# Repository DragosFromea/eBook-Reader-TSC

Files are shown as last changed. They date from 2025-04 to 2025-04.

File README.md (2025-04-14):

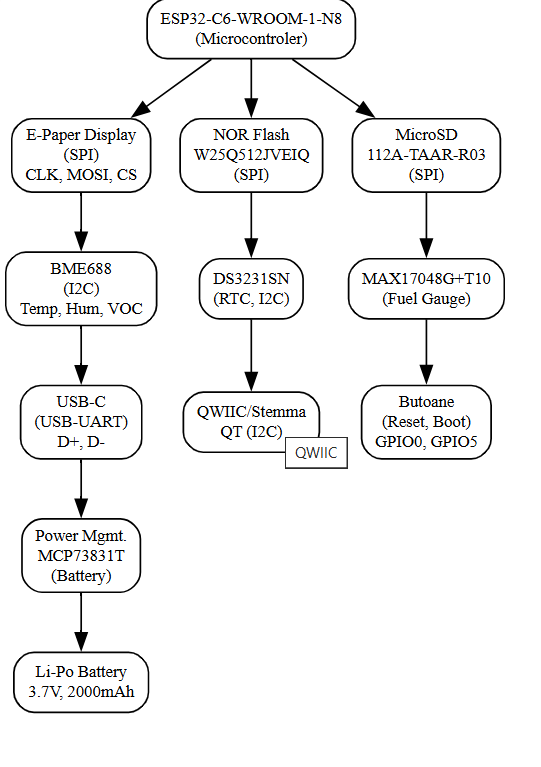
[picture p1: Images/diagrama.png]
Diagrama


| Component | Supplier Link | Datasheet |
|---|---|---|
| 112A-TAAR-R03 ATTEND | -| [Datasheet](https://www.snapeda.com/parts/112A-TAAR-R03/Attend/datasheet/)|
| BD5229G-TR | [Mouser](https://www.mouser.co.uk/ProductDetail/ROHM-Semiconductor/BD5229G-TR?qs=4kLU8WoGk0vvnhrrYwdszw%3D%3D)| [Datasheet](https://fscdn.rohm.com/en/products/databook/datasheet/ic/power/voltage_detector/bd52xxg-e.pdf) |
| CPH3225A (Supercapacitor)| [SnapEDA](https://www.snapeda.com/parts/CPH3225A/Seiko+Instruments/view-part/?ref=eda) | [Datasheet](https://www.snapeda.com/parts/CPH3225A/Seiko%20Instruments/datasheet/) |
| DS3231SN# (RTC) | [SnapEDA](https://www.snapeda.com/parts/DS3231SN%23/Analog+Devices/view-part/?ref=eda) | [Datasheet](https://www.analog.com/media/en/technical-documentation/data-sheets/DS3231.pdf) |
| ESP32-C6-WROOM-1-N8 | [SnapEDA](https://www.snapeda.com/parts/ESP32-C6-WROOM-1-N8/Espressif+Systems/view-part/?ref=eda) | [Datasheet](https://www.espressif.com/sites/default/files/documentation/esp32-c6-wroom-1_datasheet_en.pdf) |
| FH34SRJ-24S-0.5SH99 | [Mouser](https://ro.mouser.com/ProductDetail/Hirose-Connector/FH34SRJ-24S-0.5SH99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) | [Datasheet](https://www.hirose.com/product/document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) |
| MBR0530 (Schottky Diode)| [SnapEDA](https://www.snapeda.com/parts/MBR0530/Onsemi/view-part/?ref=eda) | [Datasheet](https://www.onsemi.com/pdf/datasheet/mbr0530-d.pdf) |
| MAX17048G+T10 (Fuel Gauge)| [SnapEDA](https://www.snapeda.com/parts/MAX17048G+T10/Analog+Devices/view-part/?ref=eda)| [Datasheet](https://www.analog.com/media/en/technical-documentation/data-sheets/MAX17048-MAX17049.pdf) |
| USBLC6-2SC6Y (TVS Diode)| [SnapEDA](https://www.snapeda.com/parts/USBLC6-2SC6Y/STMicroelectronics/view-part/?ref=eda)| [Datasheet](https://www.st.com/resource/en/datasheet/usblc6-2.pdf) |
| W25Q512JVEIQ (Flash) | [SnapEDA](https://www.snapeda.com/parts/W25Q512JVEIQ/Winbond+Electronics/view-part/?ref=eda)| [Datasheet](https://www.winbond.com/resource-files/W25Q512JV%20SPI%20RevB%2006252019%20KMS.pdf) |
| XC6220A331MR-G (LDO) | [Mouser](https://www.mouser.co.uk/ProductDetail/Torex-Semiconductor/XC6220A331MR-G?qs=AsjdqWjXhJ8ZSWznL1J0gg%3D%3D)| [Datasheet](https://product.torexsemi.com/system/files/series/xc6220.pdf) | |
| QWIIC Connector | - | [Datasheet](https://learn.sparkfun.com/tutorials/qwiic-shield-for-arduino--photon-hookup-guide) |

Core Components
Microcontroller (ESP32-C6-WROOM-1-N8):

    Architecture: 32-bit RISC-V

    Clock Speed: 160 MHz

    Wireless: Wi-Fi 6 (2.4 GHz), Bluetooth 5.0

    Functions: System control, sensor/module communication, power management.

Power Management
Battery System:

    Type: Li-Po (Lithium Polymer)

    Capacity: 3.7V, 1800mAh

    Charging Circuit: MCP73831T (5V input via USB-C)

    Protection: Overcharge and deep discharge safeguards.

    Voltage Regulation: LDO regulator (stable 3.3V output).

Storage & Display
E-Paper Display:

    Size: 7.5 inches | Resolution: 800×480 pixels

    Interface: SPI

MicroSD Card Module:

    Format: FAT32 | Interface: SPI

External NOR Flash:

    Capacity: 64MB | Interface: SPI

Sensors & Timing
Environmental Sensor (BME688):

    Metrics: Temperature, humidity, air pressure, gas levels.

    Interface: I2C

Real-Time Clock (DS3231SN):

    Function: Maintains time/date during power loss.

    Interface: I2C

User Interface
USB-C Connector:

    Role: Power input, data transfer.

    Safety: ESD protection + Schottky diode (reverse polarity).

Tactile Push Buttons:

    Control: GPIO-based input.

Communication Interfaces
SPI: SD card, external flash, e-paper display.

I2C: BME688 sensor, DS3231SN RTC.

GPIO: Button controls, general I/O.

UART: Debugging, serial communication.

Wireless: Wi-Fi 6/Bluetooth 5.0 (via ESP32-C6).

### Power Consumption Estimation  
| Component | Current Draw (mA) | Voltage (V) | Power (mW) |  
|---|---|---|---|
| ESP32-C6 (Wi-Fi active) | 200 | 3.3 | 660 |  
| E-Paper Display (Updating) | 40 | 3.3 | 132 |  
| BME688 Sensor (Measuring) | 3.1 | 3.3 | 10.23 |  
| RTC Module (Active) | 0.15 | 3.3 | 0.495 |  
| SD Card (Active) | 50 | 3.3 | 165 |  
| External NOR Flash | 25 | 3.3 | 82.5 |  
| **Total Estimated Power Consumption** | **~318.5 mA** | **3.3** | **1050.72**|  

---

### ESP32-C6 Pin Mapping  
| Component | ESP32-C6 Pin(s) | Interface | Purpose |  
|---|---|---|---|
| E-Paper Display | IO7 (MOSI), IO6 (SCK), IO10 (CS), IO5 (DC), IO23 (RST), IO3 (BUSY) | SPI | Transfers image data to the display and controls its state. |  
| MicroSD Card | IO7 (MOSI), IO6 (SCK), IO4 (SS_SD), IO2 (MISO) | SPI | Storage and retrieval of e-book files. |  
| Environmental Sensor (BME688)  | IO21 (SDA), IO22 (SCL) | I2C | Reads temperature, humidity, pressure, and air quality data. |  
| RTC Module (DS3231) | IO21 (SDA), IO22 (SCL), IO18 (RST), IO1 (32KHz), IO0 (INT_RTC) | I2C | Maintains time/date tracking during system power-off. |  
| External NOR Flash | IO11 (CS), IO6 (SCK), IO2 (MISO), IO7 (MOSI) | SPI | Additional storage for application data. |  
| Battery Monitoring | IO21 (SDA), IO22 (SCL) | I2C | Monitors battery voltage and charge status. |  
| USB-C Connection | GPIOs (via voltage regulation) | USB | Powers and programs the ESP32-C6. |  
| Control Buttons | IO9 (BOOT), IO15 (CHANGE), EN (RESET) | GPIO | User input for device interactions (boot, mode change, reset). |  

Am acceptat erorile SMD de overlap

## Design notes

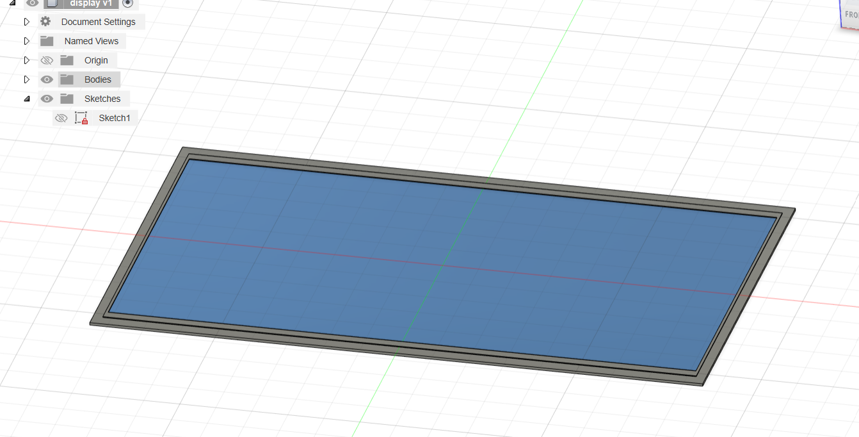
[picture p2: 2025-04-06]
Images/Screenshot 2025-04-06 185428.png

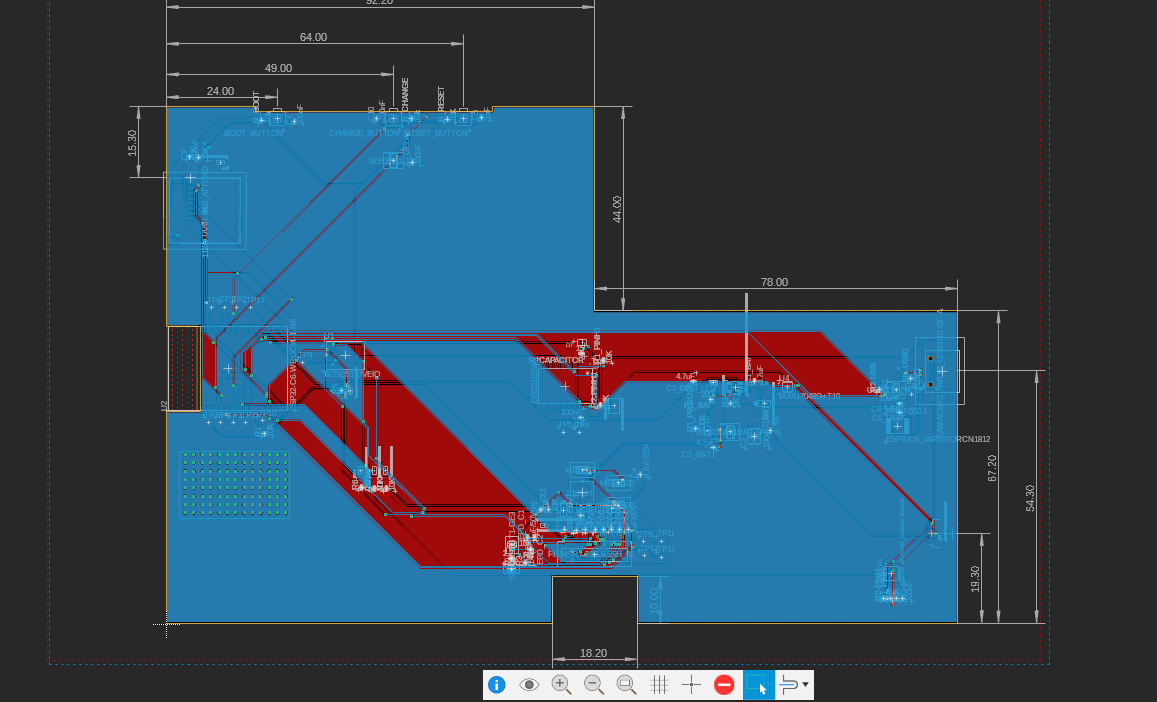
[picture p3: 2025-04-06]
Images/Screenshot 2025-04-06 185200.png

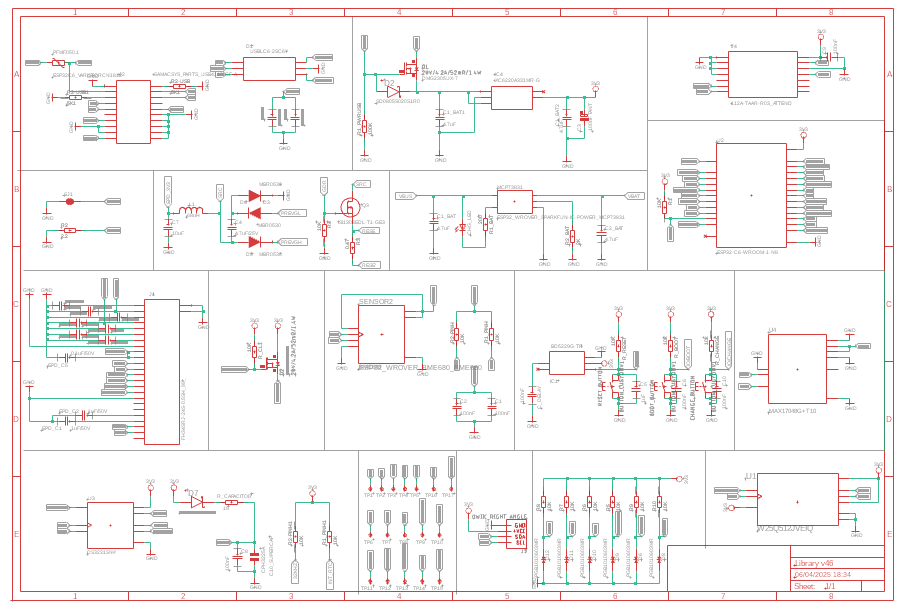
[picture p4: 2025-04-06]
Images/Screenshot 2025-04-06 185306.png

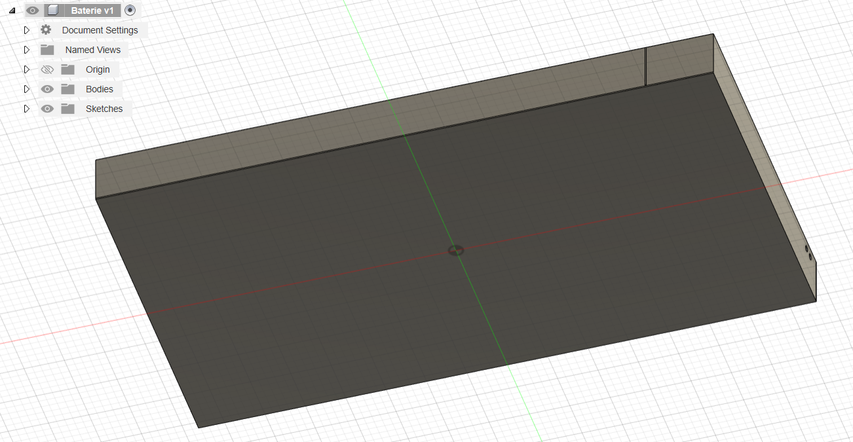
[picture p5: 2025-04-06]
Images/Screenshot 2025-04-06 185601.png

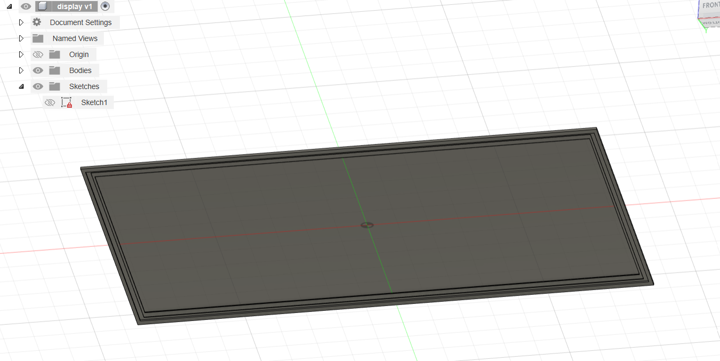
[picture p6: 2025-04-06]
Images/Screenshot 2025-04-06 185456.png

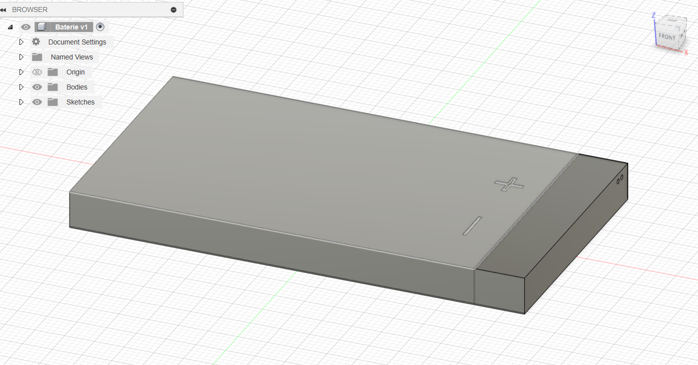
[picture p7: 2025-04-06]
Images/Screenshot 2025-04-06 185522.png

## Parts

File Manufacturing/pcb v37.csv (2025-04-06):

Qty | Value | Device | Package | Parts | Description | ARROW_PART_NUMBER | ARROW_PRICE-STOCK | AVAILABILITY | CENTROID_NOT_SPECIFIED | CHECK_PRICES | COPYRIGHT | DATASHEET | DESCRIPTION | DIGIKEY_DESCRIPTION | DIGIKEY_PART_NUMBER | HEIGHT | LEAD_FREE | MANUFACTURER_NAME | MANUFACTURER_PART_NUMBER | MF | MFR_NAME | MOUSER_PART_NUMBER | MOUSER_PRICE-STOCK | MOUSER_TESTING_PART_NUMBER | MOUSER_TESTING_PRICE-STOCK | MP | MPN | PACKAGE | POPULARITY | PREFIX | PRICE | PROD_ID | PURCHASE-URL | ROHS | SNAPEDA_LINK | SPICEMODEL | SPICEPREFIX | TEMPERATURE_RANGE_HIGH | TEMPERATURE_RANGE_LOW | TP_SIGNAL_NAME | VALUE
1 |  | ADAFRUIT_LEDCHIP-LED0603 | ADAFRUIT_CHIP-LED0603 | CHG_LED | LED
1 |  | SJ | SJ | SJ1 | SMD solder JUMPER |  |  |  |  |  |  |  |  |  |  |  |  |  |  |  |  |  |  |  |  |  |  |  | 3
1 | 0.1uF/50V | ESP32_WROVER_EAGLE-LTSPICE_CC0402 | ESP32_WROVER_EAGLE-LTSPICE_C0402 | EPD_C5 | CAPACITOR, European symbol |  |  |  |  |  |  |  |  |  |  |  |  |  |  |  |  |  |  |  |  |  |  |  |  |  |  |  |  |  |  | NONE | C
1 | 0.47 | ESP32_WROVER_EAGLE-LTSPICE_RR0402 | ESP32_WROVER_EAGLE-LTSPICE_R0402 | R3 | RESISTOR, European symbol |  |  |  |  |  |  |  |  |  |  |  |  |  |  |  |  |  |  |  |  |  |  |  |  |  |  |  |  |  |  | NONE | R
1 | 100K | ESP32_WROVER_EAGLE-LTSPICE_RR0402 | ESP32_WROVER_EAGLE-LTSPICE_R0402 | R1_PWRUSB | RESISTOR, European symbol |  |  |  |  |  |  |  |  |  |  |  |  |  |  |  |  |  |  |  |  |  |  |  |  |  |  |  |  |  |  | NONE | R
8 | 100nF | ESP32_WROVER_EAGLE-LTSPICE_CC0402 | ESP32_WROVER_EAGLE-LTSPICE_C0402 | C1, C2, C4_USB, C6, C8, C9, C10, C_DELAY | CAPACITOR, European symbol |  |  |  |  |  |  |  |  |  |  |  |  |  |  |  |  |  |  |  |  |  |  |  |  |  |  |  |  |  |  | NONE | C
1 | 100uF TANT | RCL_CPOL-EUCT3528 | RCL_CT3528 | C3 | POLARIZED CAPACITOR, European symbol |  |  |  |  |  |  |  |  |  |  |  |  |  |  |  |  |  |  |  |  |  |  |  | 0 |  |  |  |  |  |  |  | C
14 | 10K | ESP32_WROVER_EAGLE-LTSPICE_RR0402 | ESP32_WROVER_EAGLE-LTSPICE_R0402 | R1, R1_PINH, R1_PINH1, R2-PINH, R2-PINH1, R4, R5, R6, R7, R8, R9, R10, R_CL1, R_RESET | RESISTOR, European symbol |  |  |  |  |  |  |  |  |  |  |  |  |  |  |  |  |  |  |  |  |  |  |  |  |  |  |  |  |  |  | NONE | R
2 | 10k | ESP32_WROVER_EAGLE-LTSPICE_RR0402 | ESP32_WROVER_EAGLE-LTSPICE_R0402 | R_BOOT, R_CHANGE | RESISTOR, European symbol |  |  |  |  |  |  |  |  |  |  |  |  |  |  |  |  |  |  |  |  |  |  |  |  |  |  |  |  |  |  | NONE | R
1 | 10uF | ESP32_WROVER_EAGLE-LTSPICE_CC0402 | ESP32_WROVER_EAGLE-LTSPICE_C0402 | C7 | CAPACITOR, European symbol |  |  |  |  |  |  |  |  |  |  |  |  |  |  |  |  |  |  |  |  |  |  |  |  |  |  |  |  |  |  | NONE | C
1 | 112A-TAAR-R03_ATTEND | 112A-TAAR-R03_ATTEND | 112ATAARR03ATTEND | J4 | Micro SD Card Socket, Push-Push Type, Top Mount, SMT, H=1.83mm, 10u |  |  |  |  |  |  |  | Micro SD Card Socket | Push-Push Type | Top Mount | SMT | H=1.83mm | 10u |  |  | 1.9mm |  | ATTEND | 112A-TAAR-R03 ATTEND
1 | 15 | ESP32_WROVER_EAGLE-LTSPICE_RR0402 | ESP32_WROVER_EAGLE-LTSPICE_R0402 | R_CAPACITOR | RESISTOR, European symbol |  |  |  |  |  |  |  |  |  |  |  |  |  |  |  |  |  |  |  |  |  |  |  |  |  |  |  |  |  |  | NONE | R
1 | 1uF | ESP32_WROVER_EAGLE-LTSPICE_CC0402 | ESP32_WROVER_EAGLE-LTSPICE_C0402 | C5 | CAPACITOR, European symbol |  |  |  |  |  |  |  |  |  |  |  |  |  |  |  |  |  |  |  |  |  |  |  |  |  |  |  |  |  |  | NONE | C
1 | 1uF/50 | ESP32_WROVER_EAGLE-LTSPICE_CC0402 | ESP32_WROVER_EAGLE-LTSPICE_C0402 | EPD_C8 | CAPACITOR, European symbol |  |  |  |  |  |  |  |  |  |  |  |  |  |  |  |  |  |  |  |  |  |  |  |  |  |  |  |  |  |  | NONE | C
8 | 1uF/50V | ESP32_WROVER_EAGLE-LTSPICE_CC0402 | ESP32_WROVER_EAGLE-LTSPICE_C0402 | EPD_C1, EPD_C2, EPD_C6, EPD_C7, EPD_C9, EPD_C10, EPD_C11, EPD_C12 | CAPACITOR, European symbol |  |  |  |  |  |  |  |  |  |  |  |  |  |  |  |  |  |  |  |  |  |  |  |  |  |  |  |  |  |  | NONE | C
1 | 2.2 | ESP32_WROVER_EAGLE-LTSPICE_RR0402 | ESP32_WROVER_EAGLE-LTSPICE_R0402 | R2 | RESISTOR, European symbol |  |  |  |  |  |  |  |  |  |  |  |  |  |  |  |  |  |  |  |  |  |  |  |  |  |  |  |  |  |  | NONE | R
1 | 200 | ESP32_WROVER_EAGLE-LTSPICE_RR0402 | ESP32_WROVER_EAGLE-LTSPICE_R0402 | R1_BAT | RESISTOR, European symbol |  |  |  |  |  |  |  |  |  |  |  |  |  |  |  |  |  |  |  |  |  |  |  |  |  |  |  |  |  |  | NONE | R
2 | 20V/4.2A/52mO/1.4W | ESP32_WROVER_SPARKFUN-DISCRETESEMI_MOSFET_PCH-DMG2305UX-7 | ESP32_WROVER_SPARKFUN-DISCRETESEMI_SOT23-3 | Q1, Q2 | P-channel MOSFETs |  |  |  |  |  |  |  |  |  |  |  |  |  |  |  |  |  |  |  |  |  |  |  |  |  |  | TRAN-14388 |  |  |  |  |  |  |  |  | 20V/4.2A/52mO/1.4W
1 | 2K | ESP32_WROVER_EAGLE-LTSPICE_RR0402 | ESP32_WROVER_EAGLE-LTSPICE_R0402 | R2_BAT | RESISTOR, European symbol |  |  |  |  |  |  |  |  |  |  |  |  |  |  |  |  |  |  |  |  |  |  |  |  |  |  |  |  |  |  | NONE | R
5 | 4.7uF | ESP32_WROVER_EAGLE-LTSPICE_CC0402 | ESP32_WROVER_EAGLE-LTSPICE_C0402 | C1_BAT, C1_BAT1, C1_BAT2, C2_BAT, C5_USB | CAPACITOR, European symbol |  |  |  |  |  |  |  |  |  |  |  |  |  |  |  |  |  |  |  |  |  |  |  |  |  |  |  |  |  |  | NONE | C
1 | 4.7uF/25V | ESP32_WROVER_EAGLE-LTSPICE_CC0402 | ESP32_WROVER_EAGLE-LTSPICE_C0402 | C4 | CAPACITOR, European symbol |  |  |  |  |  |  |  |  |  |  |  |  |  |  |  |  |  |  |  |  |  |  |  |  |  |  |  |  |  |  | NONE | C
2 | 5K1 | ESP32_WROVER_EAGLE-LTSPICE_RR0402 | ESP32_WROVER_EAGLE-LTSPICE_R0402 | R2-USB, R2-USB1 | RESISTOR, European symbol |  |  |  |  |  |  |  |  |  |  |  |  |  |  |  |  |  |  |  |  |  |  |  |  |  |  |  |  |  |  | NONE | R
1 | 68uH | 744043680IND_4828-WE-TPC_WRE | IND_4828-WE-TPC_WRE | L1 |  |  |  |  |  |  | Copyright (C) 2024 Ultra Librarian. All rights reserved. |  |  |  |  |  |  |  | 744043680 |  | Wurth Electronics
1 | BD5229G-TR | BD5229G-TR | SOT95P280X125-5N | IC1 | Voltage Detector with Adjustable Delay Time: CMOS processes are utilized to develop high precision, low current consumption CMOS reset ICs that allow arbitrary setting of the delay time. The extensive lineup includes both Nch Open Drain and CMOS output types in a wide range of detection voltages (from 2.3V to 6.0V, in 0.1V steps), enabling selection of the ideal solution based on customer requirements. In addition, the entire series is of course both lead-free and RoHS-compliant. |  |  |  |  |  |  |  | Voltage Detector with Adjustable Delay Time: CMOS processes are utilized to develop high precision | low current consumption CMOS reset ICs that allow arbitrary setting of the delay time. The extensive lineup includes both Nch Open Drain and CMOS output types in a wide range of detection voltages (from 2.3V to 6.0V | in 0.1V steps) | enabling selection of the ideal solution based on customer requirements. In addition | the entire series is of course both lead-free and RoHS-compliant. |  |  | 1.25mm |  | ROHM Semiconductor | BD5229G-TR |  |  | 755-BD5229G-TR | https://www.mouser.co.uk/ProductDetail/ROHM-Semiconductor/BD5229G-TR?qs=4kLU8WoGk0vvnhrrYwdszw%3D%3D
3 | BUTTON_CUSYOMV1 | BUTTON_CUSYOMV1 | MYBUTTON | BOOT_BUTTON, CHANGE_BUTTON, RESET_BUTTON
1 | CPH3225A | CPH3225A | CAPCP3225X100N | C10_SUPERCAP | Cap 0.011F 3.3V 1210 Flat Check availability |  |  | Not in stock |  | https://www.snapeda.com/parts/CPH3225A/Seiko+Instruments/view-part/?ref=eda |  |  | 11 mF (EDLC) Supercapacitor 3.3 V 1210 (3225 Metric) - - |  |  |  |  |  |  | Seiko Instruments |  |  |  |  |  | CPH3225A |  | 1210 Seiko |  |  | None |  | https://www.snapeda.com/api/url_track_click_mouser/?unipart_id=562593&manufacturer=Seiko Instruments&part_name=CPH3225A&search_term=None |  | https://www.snapeda.com/parts/CPH3225A/Seiko+Instruments/view-part/?ref=snap
1 | DS3231SN# | DS3231SN# | SOIC127P1032X265-16N | U3 | Real Time Clock Serial 16-Pin SOIC W T/R Check availability |  |  | In Stock |  | https://www.snapeda.com/parts/DS3231SN%23/Analog+Devices/view-part/?ref=eda |  |  | Extremely Accurate I²C-Integrated RTC/TCXO/Crystal |  |  |  |  |  |  | Analog Devices |  |  |  |  |  | DS3231SN# |  | SOIC-16 Maxim |  |  | None |  | https://www.snapeda.com/api/url_track_click_mouser/?unipart_id=99048&manufacturer=Analog Devices&part_name=DS3231SN#&search_term=None |  | https://www.snapeda.com/parts/DS3231SN%23/Analog+Devices/view-part/?ref=snap
1 | ESP32-C6-WROOM-1-N8 | ESP32-C6-WROOM-1-N8 | XCVR_ESP32-C6-WROOM-1-N8 | U2 | Check availability |  |  | In Stock |  | https://www.snapeda.com/parts/ESP32-C6-WROOM-1-N8/Espressif+Systems/view-part/?ref=eda |  |  | Multiprotocol Modules ESP32-C6 module | Wi-Fi 6 in 2.4 GHz band | Bluetooth 5 | Zigbee 3.0 and Thread. ESP34-WROOM Compatible - ENGINEERING SAMPLE |  |  |  |  |  |  | Espressif Systems |  |  |  |  |  | ESP32-C6-WROOM-1-N8 |  | None |  |  | None |  |  |  | https://www.snapeda.com/parts/ESP32-C6-WROOM-1-N8/Espressif+Systems/view-part/?ref=snap
1 | ESP32C6_VARISTORCN1812 | ESP32C6_VARISTORCN1812 | ESP32C6_VARISTOR_CT/CN1812 | PFMF.050.1 | VARISTOR |  |  |  |  |  |  |  |  |  |  |  |  |  |  |  |  |  |  |  |  |  |  |  | 0
2 | ESP32_WROVER_AVX---SD0805S020S1R0_AVX_SD0805S020S1R0_0_0AVX_SD0805S020S1R0_0_0 | ESP32_WROVER_AVX---SD0805S020S1R0_AVX_SD0805S020S1R0_0_0AVX_SD0805S020S1R0_0_0 | ESP32_WROVER_AVX---SD0805S020S1R0_AVX_SD0805S020S1R0_0 | D2, D7 | Schottky Barrier Rectifier Diode |  |  |  | No |  |  | http://datasheets.avx.com/schottky.pdf |  | DIODE SCHOTTKY 20V 1A 0805 | 478-7800-1-ND |  | yes |  |  | AVX |  | 581-SD0805S020S1R0 |  |  |  |  |  | 0805 (2012 metric) |  | D |  |  |  | yes |  |  |  | +125°C | -55°C
1 | ESP32_WROVER_BME680_BME680 | ESP32_WROVER_BME680_BME680 | ESP32_WROVER_BME680_PSON80P300X300X100-8N | SENSOR2 | Integrated Environmental Unit |  |  | Unavailable |  |  |  |  | Integrated Environmental Unit |  |  |  |  |  |  | Bosch Sensortec |  |  |  |  |  | BME680 |  | LGA-8 Bosch Tools |  |  | None
1 | ESP32_WROVER_SPARKFUN-IC-POWER_MCP73831 | ESP32_WROVER_SPARKFUN-IC-POWER_MCP73831 | ESP32_WROVER_SPARKFUN-IC-POWER_SOT23-5 | MCP73831 | MCP73831T Li-Ion, Li-Pol Controller |  |  |  |  |  |  |  |  |  |  |  |  |  |  |  |  |  |  |  |  |  |  |  |  |  |  | IC-09995
1 | FH34SRJ-24S-0.5SH_99_ | FH34SRJ-24S-0.5SH_99_ | FH34SRJ24S05SH99 | J1 | (0.50mm) Surface Mount, Right Angle |  |  |  |  |  |  |  | 24 Position FFC | FPC Connector Contacts | (0.50mm) Surface Mount | Right Angle |  |  | 1.1mm |  | Hirose | FH34SRJ-24S-0.5SH(99) |  |  | 798-FH34SRJ24S05SH99 | https://www.mouser.co.uk/ProductDetail/Hirose-Connector/FH34SRJ-24S-0.5SH99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
1 | MAX17048G+T10 | MAX17048G+T10 | SON50P200X200X80-9N | U4 | Check availability |  |  | In Stock |  | https://www.snapeda.com/parts/MAX17048G+T10/Analog+Devices/view-part/?ref=eda |  |  | 3µA 1-Cell/2-Cell Fuel Gauge with ModelGauge |  |  |  |  |  |  | Analog Devices |  |  |  |  |  | MAX17048G+T10 |  | TDFN-8 Maxim |  |  | None |  | https://www.snapeda.com/api/url_track_click_mouser/?unipart_id=329239&manufacturer=Analog Devices&part_name=MAX17048G+T10&search_term=None |  | https://www.snapeda.com/parts/MAX17048G+T10/Analog+Devices/view-part/?ref=snap
3 | MBR0530 | MBR0530 | SOD3716X135N | D3, D4, D5 | ON SEMICONDUCTOR - MBR0530 - DIODE, SCHOTTKY, 0.5A, 30V, SOD-123 |  |  | In Stock |  | https://www.snapeda.com/parts/MBR0530/Onsemi/view-part/?ref=eda |  |  | Diode Schottky 30 V 500mA Surface Mount SOD-123 |  |  |  |  |  |  | ON Semiconductor |  |  |  |  |  | MBR0530 |  | SOD-123-2 ON Semiconductor |  |  | None |  | https://www.snapeda.com/api/url_track_click_mouser/?unipart_id=179458&manufacturer=ON Semiconductor&part_name=MBR0530&search_term=None |  | https://www.snapeda.com/parts/MBR0530/Onsemi/view-part/?ref=snap
6 | PGB1010603MR | PGB1010603MR | DIOC1608X36N | D6, D8, D9, D10, D11, D12 | Check availability |  |  | In Stock |  | https://www.snapeda.com/parts/PGB1010603MR/Littelfuse/view-part/?ref=eda |  |  | 150V (Typ) Clamp - Ipp Tvs Diode Surface Mount 0603 (1608 Metric) |  |  |  |  |  |  | Littelfuse Inc. |  |  |  |  |  | PGB1010603MR |  | 0603 Littelfuse Inc. |  |  | None |  | https://www.snapeda.com/api/url_track_click_mouser/?unipart_id=5659453&manufacturer=Littelfuse Inc.&part_name=PGB1010603MR&search_term=None |  | https://www.snapeda.com/parts/PGB1010603MR/Littelfuse/view-part/?ref=snap
1 | QWIIC_RIGHT_ANGLE | QWIIC_CONNECTORJS-1MM | JST04_1MM_RA | J3 | SparkFun I2C Standard Qwiic Connector |  |  |  |  |  |  |  |  |  |  |  |  |  |  |  |  |  |  |  |  |  |  |  |  |  |  | CONN-13694 |  |  |  |  |  |  |  |  | QWIIC_RIGHT_ANGLE
1 | SAMACSYS_PARTS_USB4110-GF-A | SAMACSYS_PARTS_USB4110-GF-A | SAMACSYS_PARTS_USB4110GFA | J2 | CONN USB 2.0 TYPE-C R/A SMT |  |  |  |  |  |  |  | CONN USB 2.0 TYPE-C R/A SMT |  |  | 3.26mm |  | GCT (GLOBAL CONNECTOR TECHNOLOGY) | USB4110-GF-A |  |  | 640-USB4110-GF-A | https://www.mouser.co.uk/ProductDetail/GCT/USB4110-GF-A?qs=KUoIvG%2F9IlYiZvIXQjyJeA%3D%3D
1 | SI1308EDL-T1-GE3 | SI1308EDL-T1-GE3 | SOT65P210X110-3N | Q3 | MOSFET N-Ch 30V 1.5A TrenchFET SC70 Vishay Si1308EDL-T1-GE3 N-channel MOSFET Transistor, 1.5 A, 30 V, 3-Pin SC-70 |  |  | In Stock |  | https://www.snapeda.com/parts/SI1308EDL-T1-GE3/Vishay+Siliconix/view-part/?ref=eda |  |  | Si1308EDL-T1-GE3 N-channel MOSFET Transistor | 1.5 A | 30 V | 3-Pin SC-70 | Siliconix / Vishay SI1308EDL-T1-GE3 |  |  |  |  |  |  | Vishay Siliconix |  |  |  |  |  | SI1308EDL-T1-GE3 |  | SOT-323 Vishay Semiconductor |  |  | None |  | https://www.snapeda.com/api/url_track_click_mouser/?unipart_id=274603&manufacturer=Vishay Siliconix&part_name=SI1308EDL-T1-GE3&search_term=None |  | https://www.snapeda.com/parts/SI1308EDL-T1-GE3/Vishay+Siliconix/view-part/?ref=snap
17 | TPTP20R | TPTP20R | TP20R | TP1, TP2, TP3, TP4, TP5, TP6, TP7, TP8, TP9, TP10, TP11, TP12, TP13, TP14, TP15, TP16, TP17 | Test pad |  |  |  |  |  |  |  |  |  |  |  |  |  |  |  |  |  |  |  |  |  |  |  | 2
1 | USBLC6-2SC6Y | USBLC6-2SC6Y | SOT95P280X145-6N | D1 | Low Cap. ESD Protection Auto SOT-23-6 STMicroelectronics USBLC6-2SC6Y, Dual Uni-Directional TVS Diode Array, 6-Pin SOT-23 |  |  | In Stock |  | https://www.snapeda.com/parts/USBLC6-2SC6Y/STMicroelectronics/view-part/?ref=eda |  |  | 17V Clamp 5A (8/20µs) Ipp Tvs Diode Surface Mount SOT-23-6 |  |  |  |  |  |  | STMicroelectronics |  |  |  |  |  | USBLC6-2SC6Y |  | SOT-23-6 STMicroelectronics |  |  | None |  |  |  | https://www.snapeda.com/parts/USBLC6-2SC6Y/STMicroelectronics/view-part/?ref=snap
1 | W25Q512JVEIQ | W25Q512JVEIQ | SON127P600X800X80-9N | U1 | Check availability |  |  | In Stock |  | https://www.snapeda.com/parts/W25Q512JVEIQ/Winbond+Electronics/view-part/?ref=eda |  |  | FLASH - NOR Memory IC 512Mb (64M x 8) SPI - Quad I/O 133 MHz 8-WSON (8x6) |  |  |  |  |  |  | Winbond Electronics |  |  |  |  |  | W25Q512JVEIQ |  | Package |  |  | None |  |  |  | https://www.snapeda.com/parts/W25Q512JVEIQ/Winbond+Electronics/view-part/?ref=snap
1 | XC6220A331MR-G | XC6220A331MR-G | SOT95P280X120-5N | IC4 | LDO Voltage Regulators |  |  |  |  |  |  |  | LDO Voltage Regulators |  |  | 1.2mm |  | Torex | XC6220A331MR-G |  |  | 865-XC6220A331MR-G | https://www.mouser.co.uk/ProductDetail/Torex-Semiconductor/XC6220A331MR-G?qs=AsjdqWjXhJ8ZSWznL1J0gg%3D%3D

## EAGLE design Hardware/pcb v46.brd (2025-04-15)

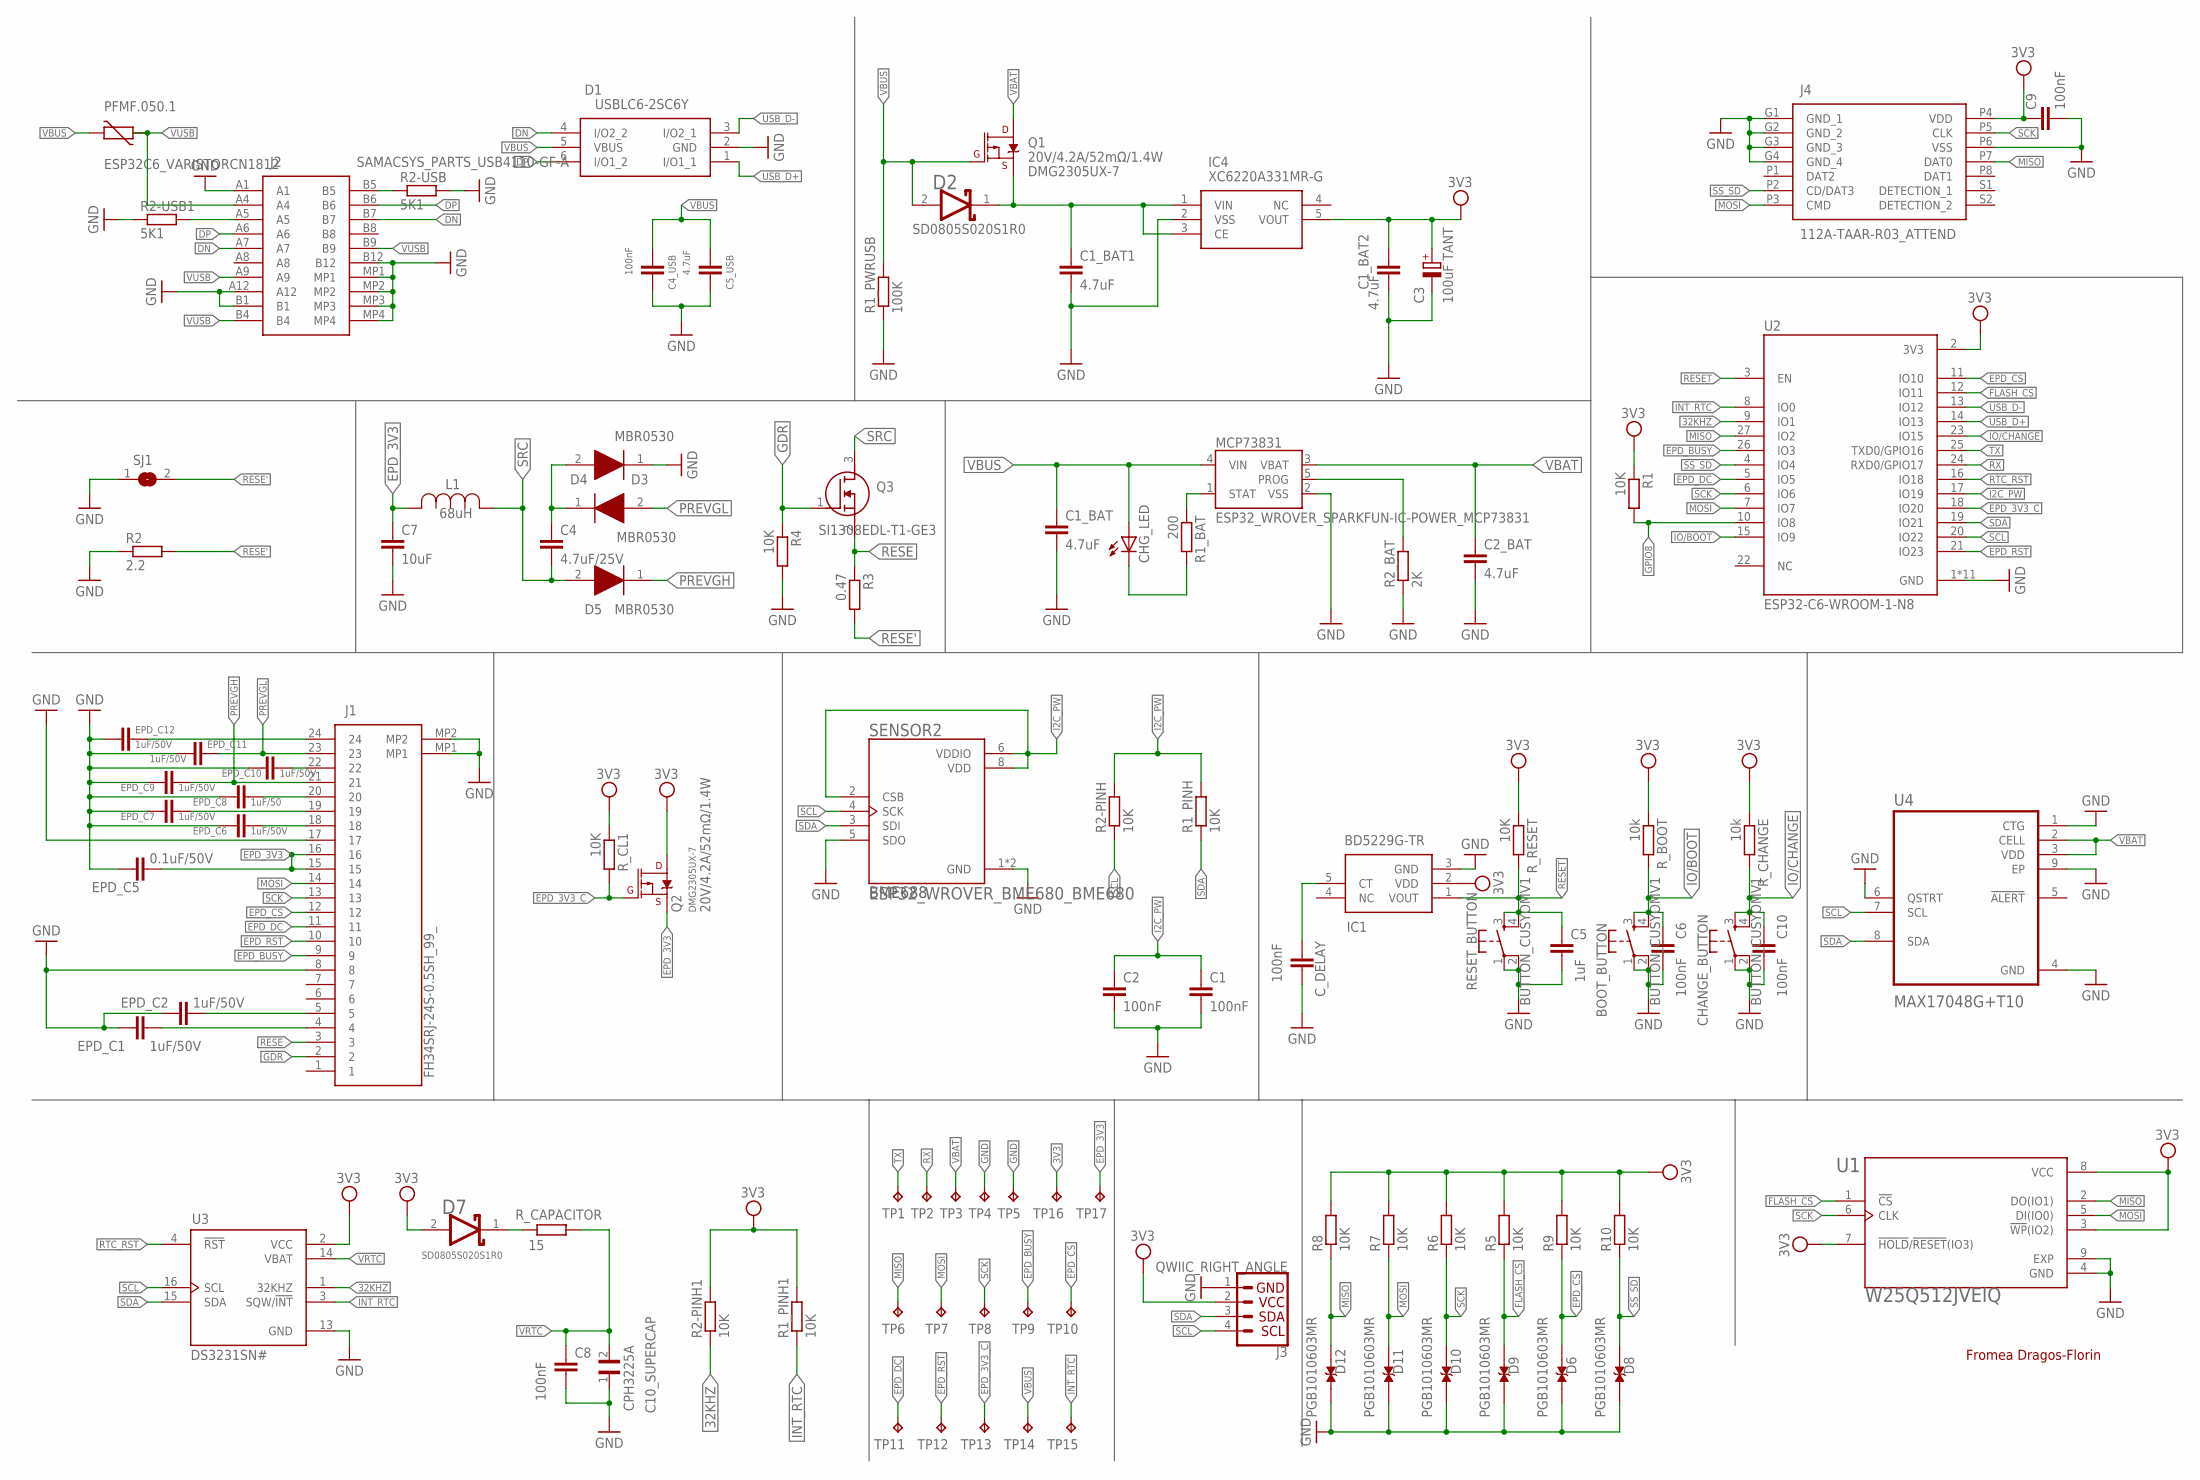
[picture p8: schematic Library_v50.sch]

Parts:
BOOT_BUTTON: BUTTON_CUSYOMV1; MYBUTTON
C1, C2, C4_USB, C6, C8, C9, C10: 100nF; ESP32_WROVER_EAGLE-LTSPICE_C0402
C1_BAT, C1_BAT1, C1_BAT2, C2_BAT, C5_USB: 4.7uF; ESP32_WROVER_EAGLE-LTSPICE_C0402
C3: 100uF TANT; RCL_CT3528
C4: 4.7uF/25V; ESP32_WROVER_EAGLE-LTSPICE_C0402
C5: 1uF; ESP32_WROVER_EAGLE-LTSPICE_C0402
C7: 10uF; ESP32_WROVER_EAGLE-LTSPICE_C0402
C10_SUPERCAP: CPH3225A; CAPCP3225X100N
CHANGE_BUTTON: BUTTON_CUSYOMV1; MYBUTTON
CHG_LED: ADAFRUIT_LEDCHIP-LED0603; ADAFRUIT_CHIP-LED0603
C_DELAY: 100nF; ESP32_WROVER_EAGLE-LTSPICE_C0402
D1: USBLC6-2SC6Y; SOT95P280X145-6N
D2, D7: ESP32_WROVER_AVX---SD0805S020S1R0_AVX_SD0805S020S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; ESP32_WROVER_AVX---SD0805S020S1R0_AVX_SD0805S020S1R0_0
D3, D4, D5: MBR0530; SOD3716X135N
D6, D8, D9, D10, D11, D12: PGB1010603MR; DIOC1608X36N
EPD_C1, EPD_C2, EPD_C6, EPD_C7, EPD_C9, EPD_C10, EPD_C11, EPD_C12: 1uF/50V; ESP32_WROVER_EAGLE-LTSPICE_C0402
EPD_C5: 0.1uF/50V; ESP32_WROVER_EAGLE-LTSPICE_C0402
EPD_C8: 1uF/50; ESP32_WROVER_EAGLE-LTSPICE_C0402
IC1: BD5229G-TR; SOT95P280X125-5N
IC4: XC6220A331MR-G; SOT95P280X120-5N
J1: FH34SRJ-24S-0.5SH_99_; FH34SRJ24S05SH99
J2: SAMACSYS_PARTS_USB4110-GF-A; SAMACSYS_PARTS_USB4110GFA
J3: QWIIC_RIGHT_ANGLE; JST04_1MM_RA
J4: 112A-TAAR-R03_ATTEND; 112ATAARR03ATTEND
L1: 68uH; IND_4828-WE-TPC_WRE
MCP73831: ESP32_WROVER_SPARKFUN-IC-POWER_MCP73831; ESP32_WROVER_SPARKFUN-IC-POWER_SOT23-5
PFMF.050.1: ESP32C6_VARISTORCN1812; ESP32C6_VARISTOR_CT/CN1812
Q1, Q2: 20V/4.2A/52mΩ/1.4W; ESP32_WROVER_SPARKFUN-DISCRETESEMI_SOT23-3
Q3: SI1308EDL-T1-GE3; SOT65P210X110-3N
R1, R1_PINH, R1_PINH1, R2-PINH, R2-PINH1, R4, R5, R6, R7, R8, R9, R10: 10K; ESP32_WROVER_EAGLE-LTSPICE_R0402
R1_BAT: 200; ESP32_WROVER_EAGLE-LTSPICE_R0402
R1_PWRUSB: 100K; ESP32_WROVER_EAGLE-LTSPICE_R0402
R2: 2.2; ESP32_WROVER_EAGLE-LTSPICE_R0402
R2-USB, R2-USB1: 5K1; ESP32_WROVER_EAGLE-LTSPICE_R0402
R2_BAT: 2K; ESP32_WROVER_EAGLE-LTSPICE_R0402
R3: 0.47; ESP32_WROVER_EAGLE-LTSPICE_R0402
RESET_BUTTON: BUTTON_CUSYOMV1; MYBUTTON
R_BOOT: 10k; ESP32_WROVER_EAGLE-LTSPICE_R0402
R_CAPACITOR: 15; ESP32_WROVER_EAGLE-LTSPICE_R0402
R_CHANGE: 10k; ESP32_WROVER_EAGLE-LTSPICE_R0402
R_CL1: 10K; ESP32_WROVER_EAGLE-LTSPICE_R0402
R_RESET: 10K; ESP32_WROVER_EAGLE-LTSPICE_R0402
SENSOR2: ESP32_WROVER_BME680_BME680; ESP32_WROVER_BME680_PSON80P300X300X100-8N
SJ1: SJ
TP1, TP2, TP3, TP4, TP5, TP6, TP7, TP8, TP9, TP10, TP11, TP12, TP13, TP14, TP15, TP16, TP17: TPTP20R; TP20R
U1: W25Q512JVEIQ; SON127P600X800X80-9N
U2: ESP32-C6-WROOM-1-N8; XCVR_ESP32-C6-WROOM-1-N8
U3: DS3231SN#; SOIC127P1032X265-16N
U4: MAX17048G+T10; SON50P200X200X80-9N

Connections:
3V3: C1_BAT2.1, C3.+, C9.1, D7.2 (ANODE), IC1.2 (VDD), IC4.5 (VOUT), J3.2, J4.P4 (VDD), Q2.3 (D), R1.1, R1_PINH1.2, R2-PINH1.2, R5.2, R6.2, R7.2, R8.2, R9.2, R10.2, R_BOOT.1, R_CHANGE.1, R_CL1.1, R_RESET.1, TP16.TP, U1.3 (!WP!(IO2)), U1.7 (!HOLD!/!RESET!(IO3)), U1.8 (VCC), U2.2 (3V3), U3.2 (VCC)
32KHZ: R2-PINH1.1, U2.9 (IO1), U3.1 (32KHZ)
DN: D1.4 (I/O2_2), J2.A7, J2.B7
DP: D1.6 (I/O1_2), J2.A6, J2.B6
EPD_3V3: C7.1, EPD_C5.1, J1.15, J1.16, L1.2, Q2.2 (S), TP17.TP
EPD_3V3_C: Q2.1 (G), R_CL1.2, TP13.TP, U2.18 (IO20)
EPD_BUSY: J1.9, TP9.TP, U2.26 (IO3)
EPD_CS: D6.2, J1.12, R9.1, TP10.TP, U2.11 (IO10)
EPD_DC: J1.11, TP11.TP, U2.5 (IO5)
EPD_RST: J1.10, TP12.TP, U2.21 (IO23)
FLASH_CS: D9.2, R5.1, U1.1 (!CS), U2.12 (IO11)
GDR: J1.2, Q3.1 (G), R4.1
GND: BOOT_BUTTON.1, BOOT_BUTTON.2, C1.2, C1_BAT.2, C1_BAT1.2, C1_BAT2.2, C2.2, C2_BAT.2, C3.-, C4_USB.2, C5.2, C5_USB.2, C6.2, C7.2, C8.2, C9.2, C10.2, C10_SUPERCAP.1, CHANGE_BUTTON.1, CHANGE_BUTTON.2, C_DELAY.2, D1.2 (GND), D4.1 (K), D6.1, D8.1, D9.1, D10.1, D11.1, D12.1, EPD_C1.2, EPD_C2.2, EPD_C5.2, EPD_C6.2, EPD_C7.2, EPD_C8.2, EPD_C9.2, EPD_C10.2, EPD_C11.2, EPD_C12.2, IC1.3 (GND), IC4.2 (VSS), J1.8, J1.17, J1.MP1, J1.MP2, J2.A1, J2.A12, J2.B1, J2.B12, J2.MP1, J2.MP2, J2.MP3, J2.MP4, J3.1, J4.G1 (GND_1), J4.G2 (GND_2), J4.G3 (GND_3), J4.G4 (GND_4), J4.P6 (VSS), MCP73831.2 (VSS), R1_PWRUSB.1, R2.1, R2-USB.2, R2-USB1.1, R2_BAT.1, R4.2, RESET_BUTTON.1, RESET_BUTTON.2, SENSOR2.1 (GND), SENSOR2.5 (SDO), SENSOR2.7 (GND), SJ1.1, TP4.TP, TP5.TP, U1.4 (GND), U1.9 (EXP), U2.1 (GND), U2.28 (GND), U2.29_1 (GND), U2.29_2 (GND), U2.29_3 (GND), U2.29_4 (GND), U2.29_5 (GND), U2.29_6 (GND), U2.29_7 (GND), U2.29_8 (GND), U2.29_9 (GND), U3.13 (GND), U4.1 (CTG), U4.4 (GND), U4.6 (QSTRT), U4.9 (EP)
GPIO8: R1.2, U2.10 (IO8)
I2C_PW: C1.1, C2.1, R1_PINH.2, R2-PINH.2, SENSOR2.2 (CSB), SENSOR2.6 (VDDIO), SENSOR2.8 (VDD), U2.17 (IO19)
INT_RTC: R1_PINH1.1, TP15.TP, U2.8 (IO0), U3.3 (SQW/!INT)
IO/BOOT: BOOT_BUTTON.3, BOOT_BUTTON.4, C6.1, R_BOOT.2, U2.15 (IO9)
IO/CHANGE: C10.1, CHANGE_BUTTON.3, CHANGE_BUTTON.4, R_CHANGE.2, U2.23 (IO15)
MISO: D12.2, J4.P7 (DAT0), R8.1, TP6.TP, U1.2 (DO(IO1)), U2.27 (IO2)
MOSI: D11.2, J1.14, J4.P3 (CMD), R7.1, TP7.TP, U1.5 (DI(IO0)), U2.7 (IO7)
unnamed: C1_BAT1.1, D2.1 (CATHODE), IC4.1 (VIN), IC4.3 (CE), Q1.2 (S)
unnamed: J2.B5, R2-USB.1
unnamed: J2.A5, R2-USB1.2
unnamed: MCP73831.1 (STAT), R1_BAT.1
unnamed: C4.1, D3.1 (K), D4.2 (A)
unnamed: CHG_LED.C, R1_BAT.2
unnamed: MCP73831.5 (PROG), R2_BAT.2
unnamed: EPD_C1.1, J1.4
unnamed: EPD_C2.1, J1.5
unnamed: EPD_C6.1, J1.18
unnamed: EPD_C7.1, J1.19
unnamed: EPD_C8.1, J1.20
unnamed: EPD_C10.1, J1.22
unnamed: C_DELAY.1, IC1.5 (CT)
unnamed: EPD_C12.1, J1.24
unnamed: D7.1 (CATHODE), R_CAPACITOR.2
PREVGH: D5.1 (K), EPD_C9.1, J1.21
PREVGL: D3.2 (A), EPD_C11.1, J1.23
RESE: J1.3, Q3.2 (S), R3.1
RESE': R2.2, R3.2, SJ1.2
RESET: C5.1, IC1.1 (VOUT), RESET_BUTTON.3, RESET_BUTTON.4, R_RESET.2, U2.3 (EN)
RTC_RST: U2.16 (IO18), U3.4 (!RST)
RX: TP2.TP, U2.24 (RXD0/GPIO17)
SCK: D10.2, J1.13, J4.P5 (CLK), R6.1, TP8.TP, U1.6 (CLK), U2.6 (IO6)
SCL: J3.4, R2-PINH.1, SENSOR2.4 (SCK), U2.20 (IO22), U3.16 (SCL), U4.7 (SCL)
SDA: J3.3, R1_PINH.1, SENSOR2.3 (SDI), U2.19 (IO21), U3.15 (SDA), U4.8 (SDA)
SRC: C4.2, D5.2 (A), L1.1, Q3.3 (D)
SS_SD: D8.2, J4.P2 (CD/DAT3), R10.1, U2.4 (IO4)
TX: TP1.TP, U2.25 (TXD0/GPIO16)
USB_D+: D1.1 (I/O1_1), U2.14 (IO13)
USB_D-: D1.3 (I/O2_1), U2.13 (IO12)
VBAT: C2_BAT.1, MCP73831.3 (VBAT), Q1.3 (D), TP3.TP, U4.2 (CELL), U4.3 (VDD)
VBUS: C1_BAT.1, C4_USB.1, C5_USB.1, CHG_LED.A, D1.5 (VBUS), D2.2 (ANODE), MCP73831.4 (VIN), PFMF.050.1.2, Q1.1 (G), R1_PWRUSB.2, TP14.TP
VRTC: C8.1, C10_SUPERCAP.2, R_CAPACITOR.1, U3.14 (VBAT)
VUSB: J2.A4, J2.A9, J2.B4, J2.B9, PFMF.050.1.1

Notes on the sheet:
DMG2305UX-7
SD0805S020S1R0
BME688
Fromea Dragos-Florin

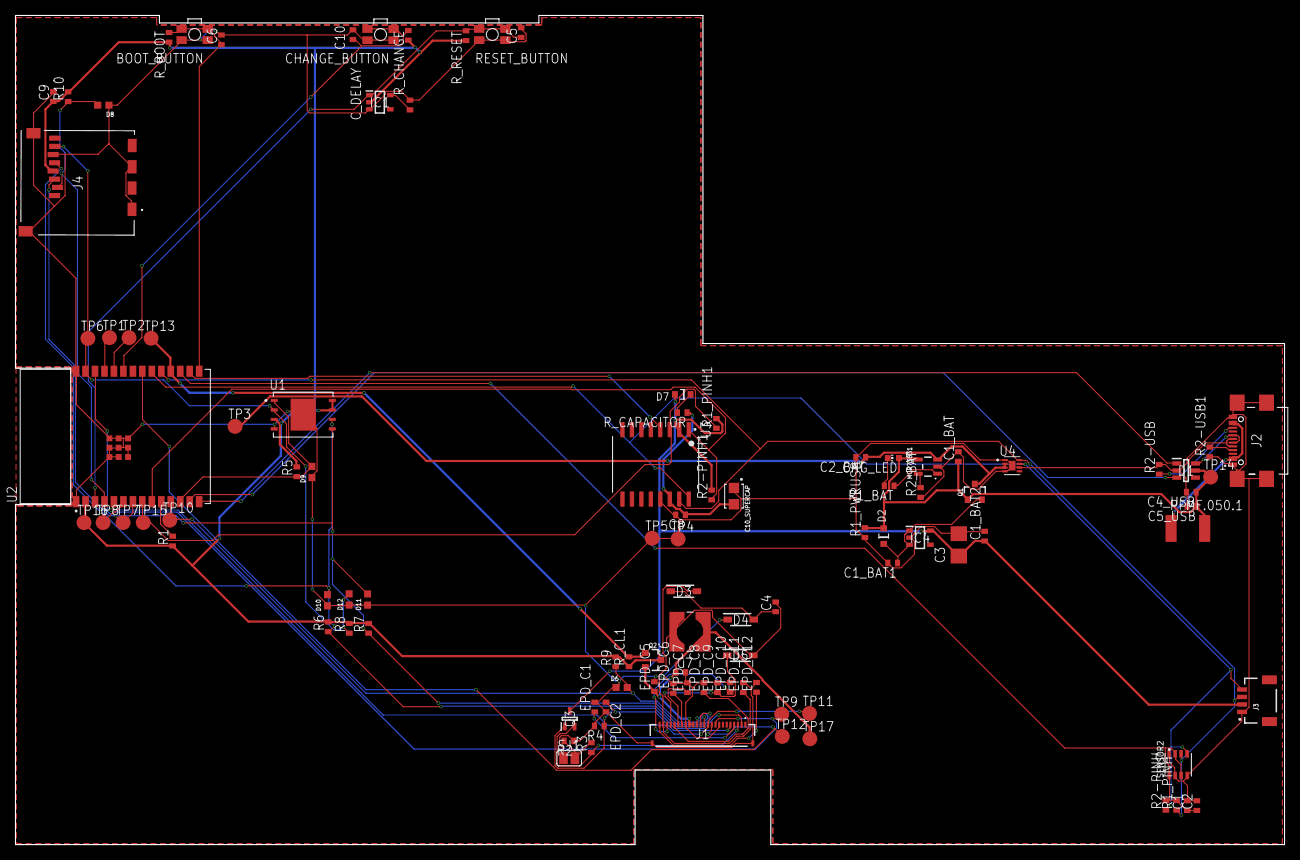
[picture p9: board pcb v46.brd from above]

Board: 2 copper layers, 170.2 x 111.2 mm, 103 parts (0 on the bottom side), 55 nets.

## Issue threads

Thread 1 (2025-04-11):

Fir lasat in aer in schematic

Scarlett-stack, 2025-04-11:
Schematic: Ai legat din greseala cu fir din ala verde aka net marginea de la cadru si iti da un warning in schematic (No pins on net N$1) langa U4 (poti rula erc din meniul de sus sa vezi si dai click pe warning si te duce unde e problema)

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

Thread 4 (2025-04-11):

Piesa lipsa pcb model 3d

Scarlett-stack, 2025-04-11:
Lipseste piesa J3 din pcb-ul 3d
O poti gasi aici: https://www.snapeda.com/parts/PRT-14417/SparkFun%20Electronics/view-part/?ref=search&t=qwiic

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

Closed 2025-04-15.

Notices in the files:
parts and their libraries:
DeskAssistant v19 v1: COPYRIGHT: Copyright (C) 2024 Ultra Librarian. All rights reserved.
